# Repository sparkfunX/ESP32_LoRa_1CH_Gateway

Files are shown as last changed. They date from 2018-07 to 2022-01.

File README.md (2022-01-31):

SparkX ESP32 LoRa Single-Channel Gateway
========================================

This repo is the original SparkX version. Please see the [SparkFun repo](https://github.com/sparkfun/ESP32_LoRa_1Ch_Gateway/) for the latest and greatest.

SparkX ESP32 LoRa Single-Channel Gateway (https://www.sparkfun.com/products/14893)

[*SparkX  ESP32 LoRa Single-Channel Gateway (SPX-14893)*](https://www.sparkfun.com/products/14893)

The SparkX ESP32 LoRa Single-Channel Gateway combines an ESP32 -- a programmable microcontroller featuring both WiFi and Bluetooth radios -- with an RFM95W LoRa transceiver to create a single-channel LoRa gateway. It's a perfect, low-cost tool for monitoring a dozen-or-so LoRa devices, and relaying their messages up to the cloud.

Complete with a [Qwiic connector](https://www.sparkfun.com/qwiic) and a breadboard-compatible array of ESP32 pin-breakouts, this board can can also serve as a general-purpose ESP32/RFM95W development platform. So, instead of using it as a LoRaWAN gateway, you can turn it into a **LoRa device**, and use the powerful ESP32 microcontroller to monitor sensors, host a web server, run a display or more.

These boards are a great way to begin dipping your toes into the world of LoRa and LoRaWAN. Not only can they be programmed as versatile single-channel gateway, but they can also be used as a LoRa device, or a general ESP32/RFM95W development board.

For more information, check out our [ESP32 LoRa 1-CH Gateway, LoRaWAN, and the Things Network](https://learn.sparkfun.com/tutorials/esp32-lora-1-ch-gateway-lorawan-and-the-things-network) tutorial, which explains how to set the board up, and get it connected to The Things Network.

SparkFun labored with love to create this code. Feel like supporting open source hardware? 
Buy a [breakout board](https://www.sparkfun.com/products/14893) from SparkFun!

Repository Contents
-------------------

* **/Documents** - Datasheets
* **/Hardware** - Eagle design files (.brd, .sch)
* **/Firmware** - Example code and esp32-Arduino board files

License Information
-------------------

This product is _**open source**_! 

If you have any questions or concerns on licensing, please contact techsupport@sparkfun.com.

Please use, reuse, and modify these files as you see fit. Please maintain attribution to SparkFun Electronics and release any derivative under the same license.

Distributed as-is; no warranty is given.

- Your friends at SparkFun.

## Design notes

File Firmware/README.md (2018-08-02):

Software directory contents
===========================

* **ESP-1CH-TTN-Device-ABP** -- Arduino example sketch implementing a single-channel LoRaWAN device with ABP activation.
	* Depends on the [Arduino-LMIC library](https://github.com/mcci-catena/arduino-lmic).
* **arduino-esp32** -- board.txt and pin-variant files to add the SparkX ESP32 LoRa 1-CH Gateway to the ESP32 Arduino core
	* Depends on the [Arduino Core for ESP32 WiFi chip](https://github.com/espressif/arduino-esp32)

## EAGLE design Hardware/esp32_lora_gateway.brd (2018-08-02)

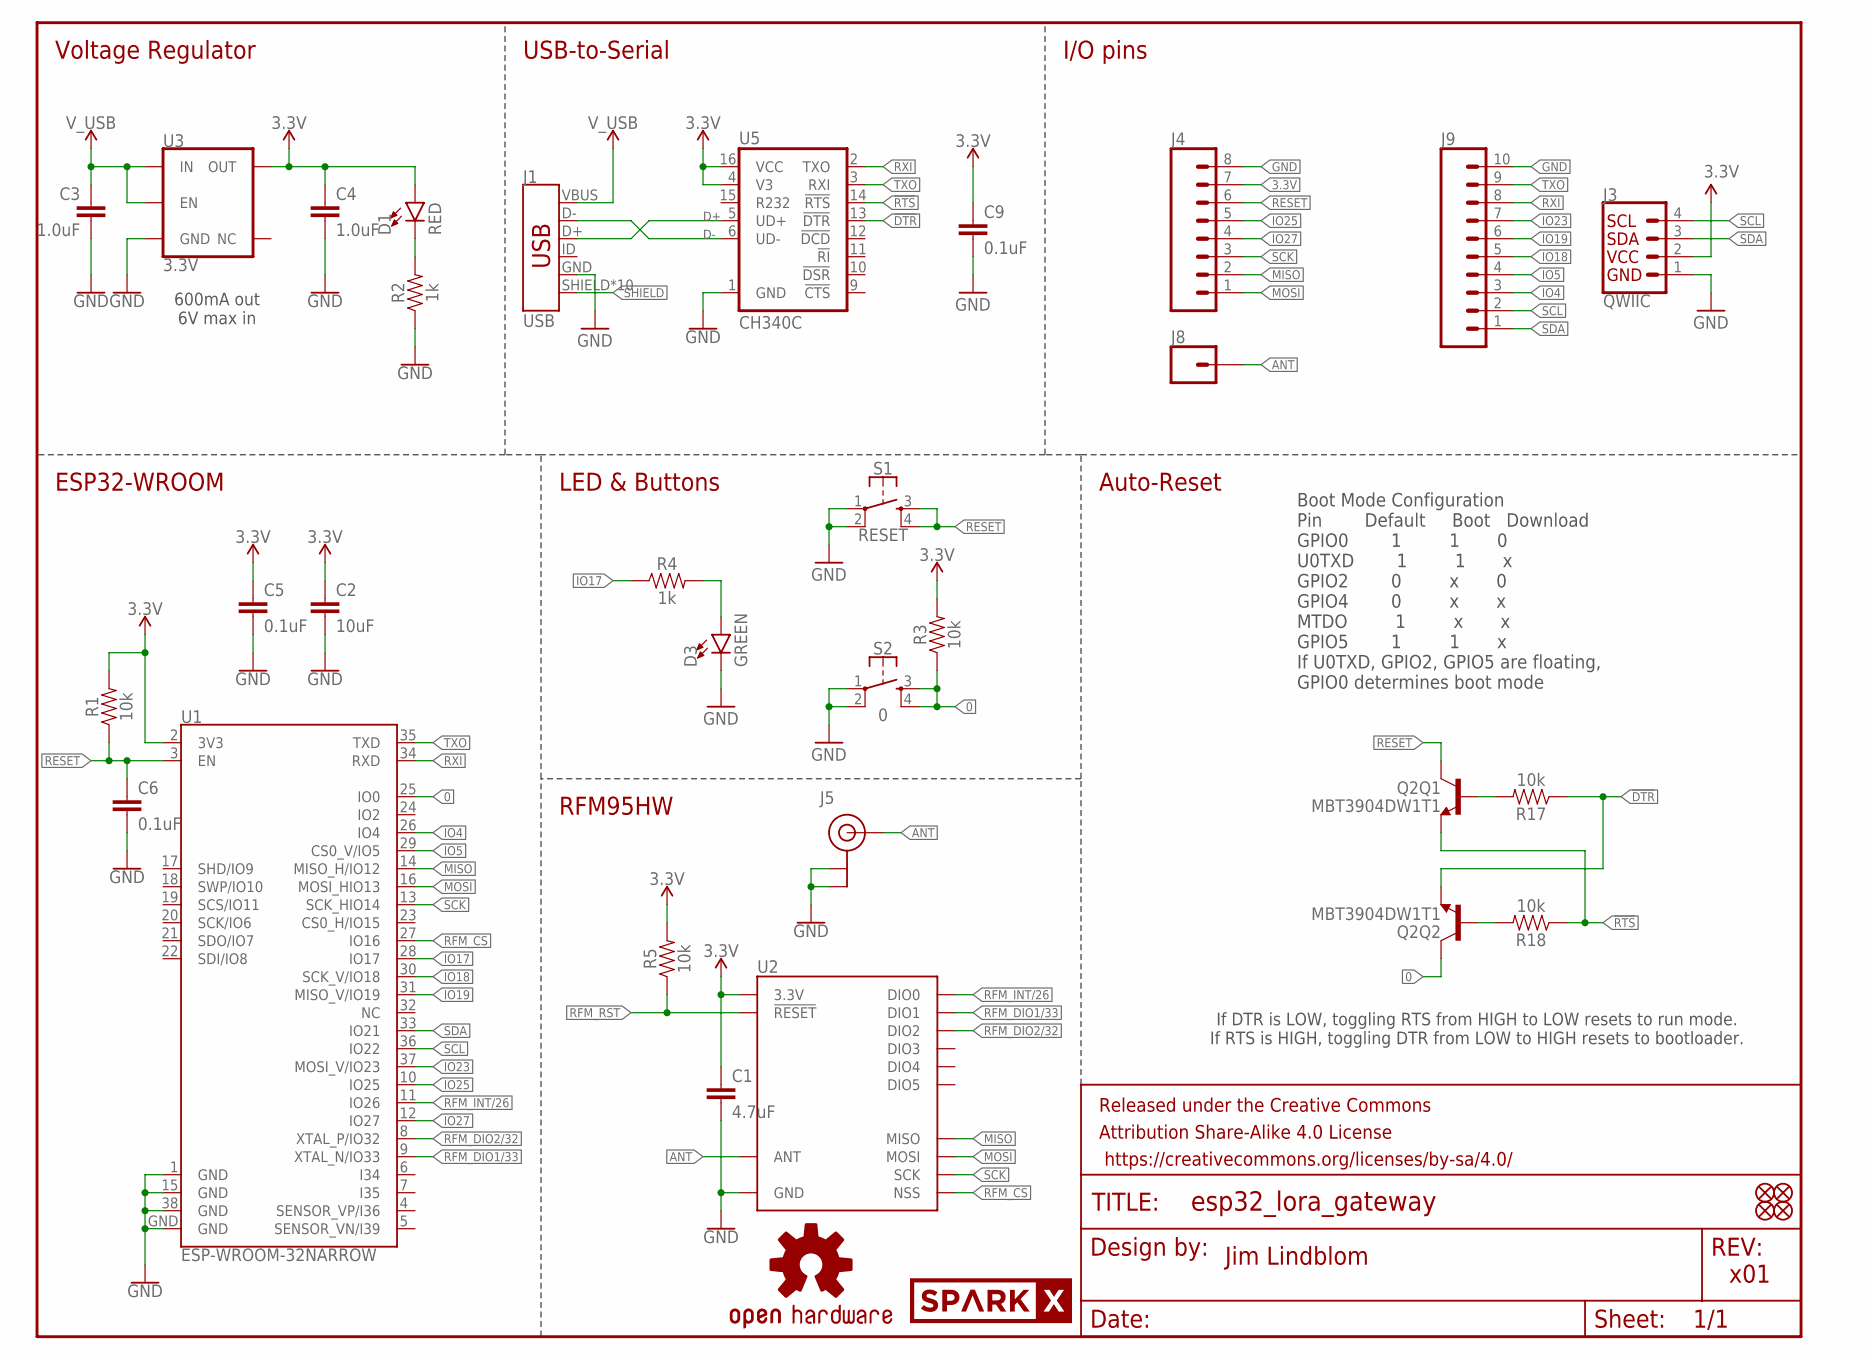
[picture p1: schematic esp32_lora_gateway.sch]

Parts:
C1: 4.7uF; 0603
C2: 10uF; 0603
C3, C4: 1.0uF; 0603
C5, C6: 0.1uF; 0603
C9: 0.1uF; 0603-CAP
D1: RED; LED-0603
D3: GREEN; LED-0603
FD1, FD2, FD3, FD4: FIDUCIALUFIDUCIAL; FIDUCIAL-MICRO
FRAME1: FRAME-LETTER; CREATIVE_COMMONS
J1: USB; USB-MICROB-PTH-MILL
J3: QWIIC; 1X04_1MM_RA
J4: CONN_08NO_SILK_FEMALE_PTH; 1X08_NO_SILK
J5: U.FL
J8: CONN_01PTH_NO_SILK_YES_STOP; 1X01_NO_SILK
J9: CONN_10NO_SILK_PTH_FEMALE; 1X10_NO_SILK
LOGO1: SPARKX-LOGO4; SPARKX-MEDIUM
LOGO2: OSHW-LOGOM; OSHW-LOGO-M
Q2: MBT3904DW1T1; SC70-6
R1, R3, R5, R17, R18: 10k; 0603
R2, R4: 1k; 0603
S1: RESET; TACTILE_SWITCH_SMD_4.6X2.8MM
S2: 0; TACTILE_SWITCH_SMD_4.6X2.8MM
U1: ESP-WROOM-32NARROW; ESP-WROOM-32-NARROW
U2: RFM96W; RFM95/96/97/98W
U3: 3.3V; SOT23-5
U5: CH340C; SO016

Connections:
0: Q2.6 (C), R3.1, S2.3, S2.4, U1.25 (IO0)
3.3V: C1.1, C2.1, C4.1, C5.1, C9.1, D1.A, J3.2, J4.7, R1.2, R3.2, R5.2, U1.2 (3V3), U2.3.3V, U3.5 (OUT), U5.4 (V3), U5.16 (VCC)
!DTR: Q2.1 (E), R17.1, U5.13 (!DTR)
!RTS: Q2.4 (E), R18.1, U5.14 (!RTS)
ANT: J5.FEED (SIGNAL), J8.1, U2.ANT
D+: J1.D+, U5.5 (UD+)
D-: J1.D-, U5.6 (UD-)
GND: C1.2, C2.2, C3.2, C4.2, C5.2, C6.2, C9.2, D3.C, J1.GND, J3.1, J4.8, J5.1 (GND), J5.2 (GND), J9.10, R2.1, S1.1, S1.2, S2.1, S2.2, U1.1 (GND), U1.15 (GND), U1.38 (GND), U1.GND, U2.GND@1 (GND), U2.GND@2 (GND), U2.GND@3 (GND), U3.2 (GND), U5.1 (GND)
IO4: J9.3, U1.26 (IO4)
IO5: J9.4, U1.29 (CS0_V/IO5)
IO17: R4.1, U1.28 (IO17)
IO18: J9.5, U1.30 (SCK_V/IO18)
IO19: J9.6, U1.31 (MISO_V/IO19)
IO23: J9.7, U1.37 (MOSI_V/IO23)
IO25: J4.5, U1.10 (IO25)
IO27: J4.4, U1.12 (IO27)
MISO: J4.2, U1.14 (MISO_H/IO12), U2.MISO
MOSI: J4.1, U1.16 (MOSI_HIO13), U2.MOSI
unnamed: D1.C, R2.2
unnamed: D3.A, R4.2
unnamed: Q2.5 (B), R17.2
unnamed: Q2.2 (B), R18.2
RESET: C6.1, J4.6, Q2.3 (C), R1.1, S1.3, S1.4, U1.3 (EN)
RFM_CS: U1.27 (IO16), U2.NSS
RFM_DIO1/33: U1.9 (XTAL_N/IO33), U2.DIO1
RFM_DIO2/32: U1.8 (XTAL_P/IO32), U2.DIO2
RFM_INT/26: U1.11 (IO26), U2.DIO0
RFM_RST: R5.1, U2.!RESET
RXI: J9.8, U1.34 (RXD), U5.2 (TXO)
SCK: J4.3, U1.13 (SCK_HIO14), U2.SCK
SCL: J3.4, J9.2, U1.36 (IO22)
SDA: J3.3, J9.1, U1.33 (IO21)
SHIELD: J1.SHIELD, J1.SHIELD2 (SHIELD), J1.SHIELD3 (SHIELD), J1.SHIELD4 (SHIELD), J1.SHIELD5 (SHIELD), J1.SHIELD6 (SHIELD), J1.SHIELD7 (SHIELD), J1.SHIELD8 (SHIELD), J1.SHIELD9 (SHIELD), J1.SHIELD10 (SHIELD)
TXO: J9.9, U1.35 (TXD), U5.3 (RXI)
V_USB: C3.1, J1.VBUS, U3.1 (IN), U3.3 (EN)

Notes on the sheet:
Boot Mode Configuration Pin Default Boot Download GPIO0 1 1 0 U0TXD 1 1 x GPIO2 0 x 0 GPIO4 0 x x MTDO 1 x x GPIO5 1 1 x If U0TXD, GPIO2, GPIO5 are floating, GPIO0 determines boot mode
If DTR is LOW, toggling RTS from HIGH to LOW resets to run mode. If RTS is HIGH, toggling DTR from LOW to HIGH resets to bootloader.
600mA out 6V max in
Voltage Regulator
USB-to-Serial
I/O pins
ESP32-WROOM
LED & Buttons
Auto-Reset
RFM95HW
Jim Lindblom
x01

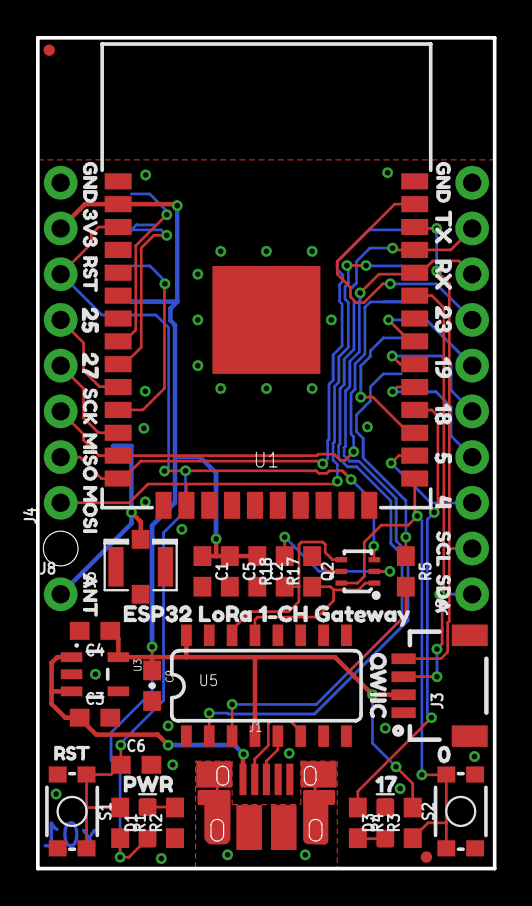
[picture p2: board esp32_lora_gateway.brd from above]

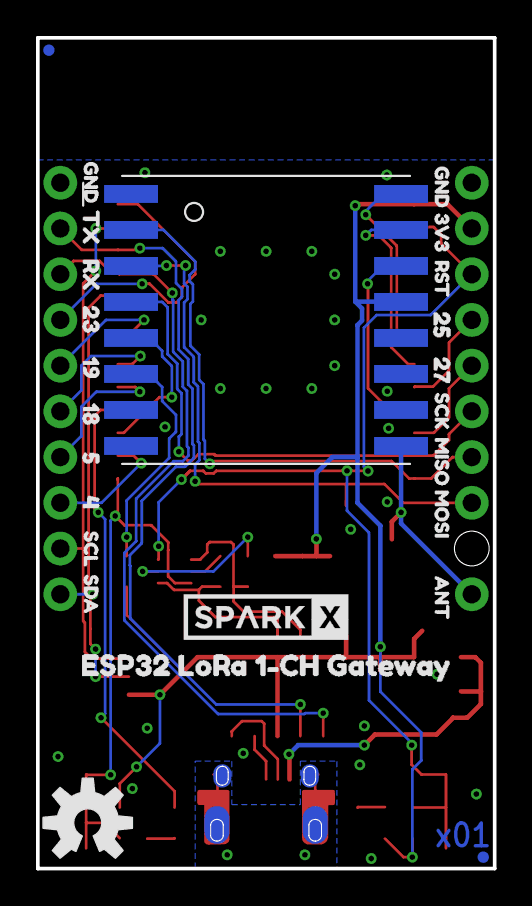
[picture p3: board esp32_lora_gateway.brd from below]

Board: 2 copper layers, 25.4 x 46.2 mm, 81 parts (25 on the bottom side), 35 nets.

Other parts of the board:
U$1, U$10, U$26, U$37: GND0
U$2, U$38: 3V31
U$3, U$20, U$39: RST2
U$4, U$40: 2517
U$5, U$41: 279
U$6, U$42: SCK3
U$7, U$43: MISO4
U$8, U$44: MOSI5
U$9, U$36: ANT6
U$11, U$27: TX16
U$12, U$28: RX15
U$13, U$29: 2314
U$14, U$30: 1912
U$15, U$31: 1811
U$16, U$32: 513
U$17, U$33: 410
U$18, U$34: SCL8
U$19, U$35: SDA7
U$21: 020
U$22: PWR19
U$23: 1722
U$24: QWIIC18
U$25: ESP32_LORA_1#CH_GATEWAY21
U$45: ESP32_LORA_1#CH_GATEWAY23

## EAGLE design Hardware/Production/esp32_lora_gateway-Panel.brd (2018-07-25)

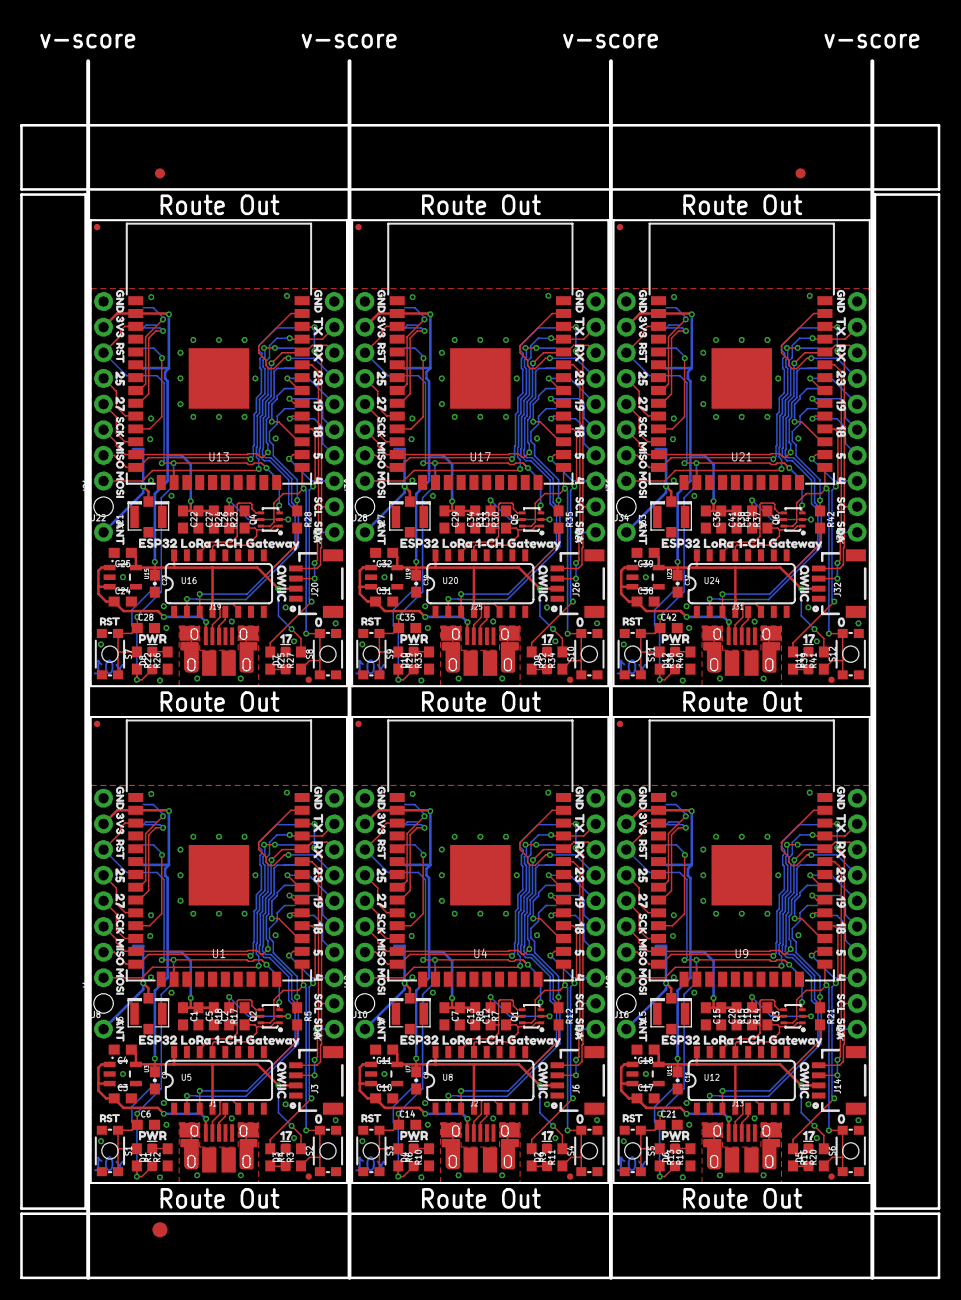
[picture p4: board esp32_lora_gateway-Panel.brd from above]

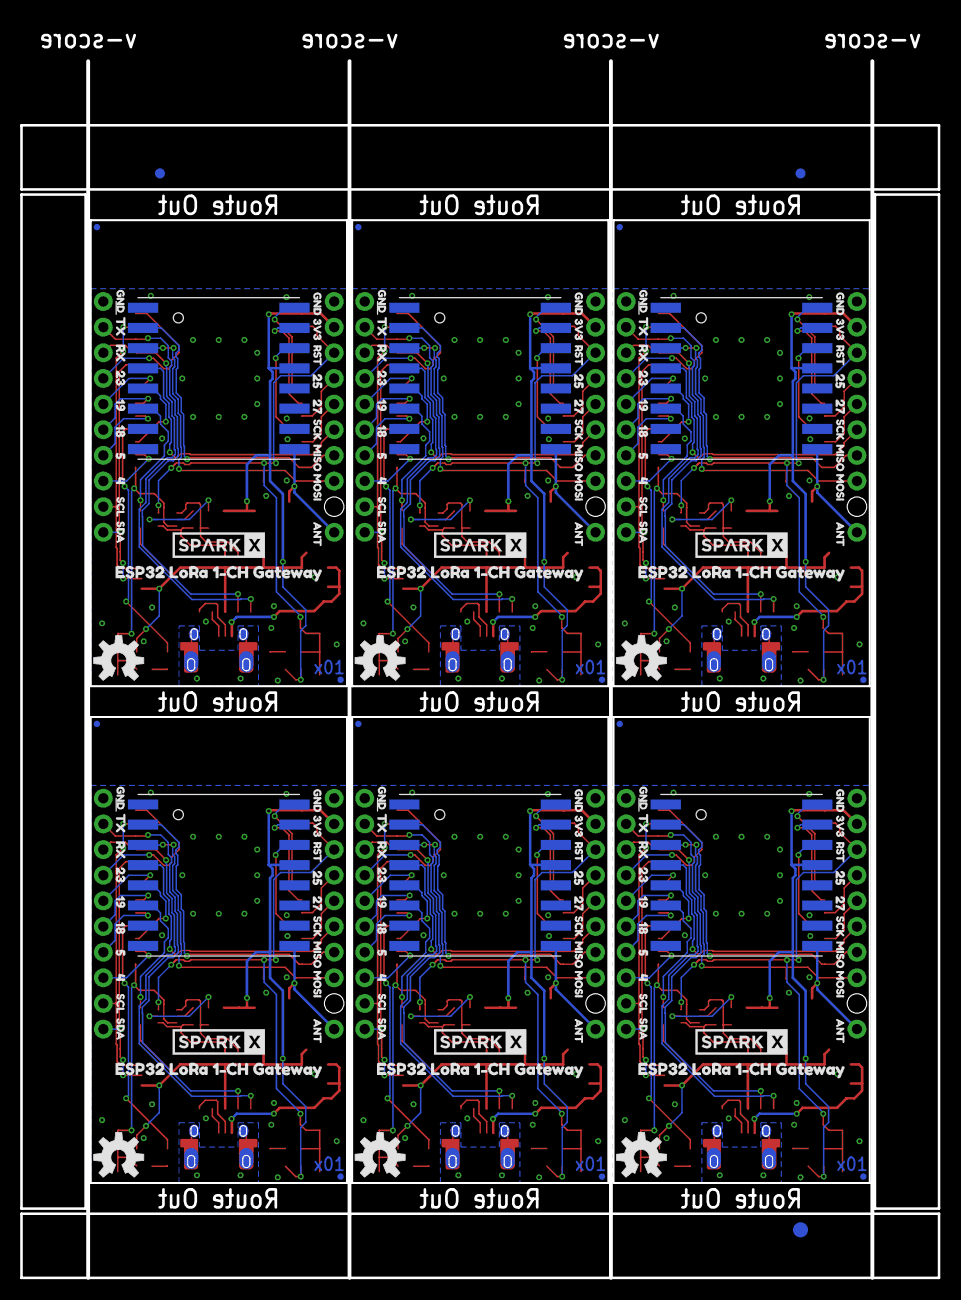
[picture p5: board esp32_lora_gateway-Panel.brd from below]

Board: 2 copper layers, 90.9 x 120.5 mm, 486 parts (153 on the bottom side), 210 nets.

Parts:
C1, C7, C15, C22, C29, C36: 4.7uF; 0603
C2, C12, C19, C26, C33, C40: 10uF; 0603
C3, C4, C10, C11, C17, C18, C24, C25, C31, C32, C38, C39: 1.0uF; 0603
C5, C6, C13, C14, C20, C21, C27, C28, C34, C35, C41, C42: 0.1uF; 0603
C8, C9, C16, C23, C30, C37: 0.1uF; 0603-CAP
D1, D4, D6, D8, D10, D12: RED; LED-0603
D2, D3, D5, D7, D9, D11: GREEN; LED-0603
E$1, E$2, E$3, E$4: FIDUCIAL-1X2
E$5, E$6: FIDUCIAL-1.5X3
FD1, FD2, FD3, FD4, FD5, FD6, FD7, FD8, FD9, FD10, FD11, FD12, FD13, FD14, FD15, FD16, FD17, FD18, FD19, FD20, FD21, FD22, FD23, FD24: FIDUCIALUFIDUCIAL; FIDUCIAL-MICRO
J1, J2, J13, J19, J25, J31: USB-MICROB-PTH-MILL
J3, J6, J14, J20, J26, J32: 1X04_1MM_RA
J4, J12, J18, J24, J30, J36: 1X08_NO_SILK
J5, J7, J15, J21, J27, J33: U.FL
J8, J10, J16, J22, J28, J34: 1X01_NO_SILK
J9, J11, J17, J23, J29, J35: 1X10_NO_SILK
LOGO1, LOGO3, LOGO5, LOGO7, LOGO9, LOGO11: SPARKX-LOGO4; SPARKX-MEDIUM
LOGO2, LOGO4, LOGO6, LOGO8, LOGO10, LOGO12: OSHW-LOGOM; OSHW-LOGO-M
Q1, Q2, Q3, Q4, Q5, Q6: MBT3904DW1T1; SC70-6
R1, R3, R5, R6, R7, R8, R11, R12, R13, R14, R15, R17, R18, R20, R21, R22, R23, R24, R27, R28, R29, R30, R31, R34, R35, R36, R37, R38, R41, R42: 10k; 0603
R2, R4, R9, R10, R16, R19, R25, R26, R32, R33, R39, R40: 1k; 0603
S1, S2, S3, S4, S5, S6, S7, S8, S9, S10, S11, S12: RESET; TACTILE_SWITCH_SMD_4.6X2.8MM
U1, U4, U9, U13, U17, U21: ESP-WROOM-32NARROW; ESP-WROOM-32-NARROW
U2, U6, U10, U14, U18, U22: RFM96W; RFM95/96/97/98W
U3, U7, U11, U15, U19, U23: 3.3V; SOT23-5
U5, U8, U12, U16, U20, U24: CH340C; SO016
U$1, U$10, U$26, U$37, U$47, U$55, U$71, U$82, U$92, U$100, U$116, U$127, U$137, U$145, U$161, U$172, U$182, U$190, U$206, U$217, U$227, U$235, U$251, U$262: GND0
U$2, U$38, U$48, U$83, U$93, U$128, U$138, U$173, U$183, U$218, U$228, U$263: 3V31
U$3, U$20, U$39, U$49, U$65, U$84, U$94, U$110, U$129, U$139, U$155, U$174, U$184, U$200, U$219, U$229, U$245, U$264: RST2
U$4, U$40, U$50, U$85, U$95, U$130, U$140, U$175, U$185, U$220, U$230, U$265: 2517
U$5, U$41, U$51, U$86, U$96, U$131, U$141, U$176, U$186, U$221, U$231, U$266: 279
U$6, U$42, U$52, U$87, U$97, U$132, U$142, U$177, U$187, U$222, U$232, U$267: SCK3
U$7, U$43, U$53, U$88, U$98, U$133, U$143, U$178, U$188, U$223, U$233, U$268: MISO4
U$8, U$44, U$54, U$89, U$99, U$134, U$144, U$179, U$189, U$224, U$234, U$269: MOSI5
U$9, U$36, U$46, U$81, U$91, U$126, U$136, U$171, U$181, U$216, U$226, U$261: ANT6
U$11, U$27, U$56, U$72, U$101, U$117, U$146, U$162, U$191, U$207, U$236, U$252: TX16
U$12, U$28, U$57, U$73, U$102, U$118, U$147, U$163, U$192, U$208, U$237, U$253: RX15
U$13, U$29, U$58, U$74, U$103, U$119, U$148, U$164, U$193, U$209, U$238, U$254: 2314
U$14, U$30, U$59, U$75, U$104, U$120, U$149, U$165, U$194, U$210, U$239, U$255: 1912
U$15, U$31, U$60, U$76, U$105, U$121, U$150, U$166, U$195, U$211, U$240, U$256: 1811
U$16, U$32, U$61, U$77, U$106, U$122, U$151, U$167, U$196, U$212, U$241, U$257: 513
U$17, U$33, U$62, U$78, U$107, U$123, U$152, U$168, U$197, U$213, U$242, U$258: 410
U$18, U$34, U$63, U$79, U$108, U$124, U$153, U$169, U$198, U$214, U$243, U$259: SCL8
U$19, U$35, U$64, U$80, U$109, U$125, U$154, U$170, U$199, U$215, U$244, U$260: SDA7
U$21, U$66, U$111, U$156, U$201, U$246: 020
U$22, U$67, U$112, U$157, U$202, U$247: PWR19
U$23, U$68, U$113, U$158, U$203, U$248: 1722
U$24, U$69, U$114, U$159, U$204, U$249: QWIIC18
U$25, U$70, U$115, U$160, U$205, U$250: ESP32_LORA_1#CH_GATEWAY21
U$45, U$90, U$135, U$180, U$225, U$270: ESP32_LORA_1#CH_GATEWAY23

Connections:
0: Q2.6, R3.1, S2.3, S2.4, U1.25
1: Q1.6, R11.1, S4.3, S4.4, U4.25
2: Q3.6, R20.1, S6.3, S6.4, U9.25
3: Q4.6, R27.1, S8.3, S8.4, U13.25
3.3V: C1.1, C2.1, C4.1, C5.1, C9.1, D1.A, J3.2, J4.7, R1.2, R3.2, R5.2, U1.2, U2.3.3V, U3.5, U5.4, U5.16
3.3V1: C7.1, C8.1, C11.1, C12.1, C13.1, D4.A, J6.2, J12.7, R6.2, R11.2, R12.2, U4.2, U6.3.3V, U7.5, U8.4, U8.16
3.3V2: C15.1, C16.1, C18.1, C19.1, C20.1, D6.A, J14.2, J18.7, R13.2, R20.2, R21.2, U9.2, U10.3.3V, U11.5, U12.4, U12.16
3.3V3: C22.1, C23.1, C25.1, C26.1, C27.1, D8.A, J20.2, J24.7, R22.2, R27.2, R28.2, U13.2, U14.3.3V, U15.5, U16.4, U16.16
3.3V4: C29.1, C30.1, C32.1, C33.1, C34.1, D10.A, J26.2, J30.7, R29.2, R34.2, R35.2, U17.2, U18.3.3V, U19.5, U20.4, U20.16
3.3V5: C36.1, C37.1, C39.1, C40.1, C41.1, D12.A, J32.2, J36.7, R36.2, R41.2, R42.2, U21.2, U22.3.3V, U23.5, U24.4, U24.16
4: Q5.6, R34.1, S10.3, S10.4, U17.25
5: Q6.6, R41.1, S12.3, S12.4, U21.25
!DTR: Q2.1, R17.1, U5.13
!DTR1: Q1.1, R7.1, U8.13
!DTR2: Q3.1, R14.1, U12.13
!DTR3: Q4.1, R23.1, U16.13
!DTR4: Q5.1, R30.1, U20.13
!DTR5: Q6.1, R37.1, U24.13
!RTS: Q2.4, R18.1, U5.14
!RTS1: Q1.4, R8.1, U8.14
!RTS2: Q3.4, R15.1, U12.14
!RTS3: Q4.4, R24.1, U16.14
!RTS4: Q5.4, R31.1, U20.14
!RTS5: Q6.4, R38.1, U24.14
ANT: J5.FEED, J8.1, U2.ANT
ANT1: J7.FEED, J10.1, U6.ANT
ANT2: J15.FEED, J16.1, U10.ANT
ANT3: J21.FEED, J22.1, U14.ANT
ANT4: J27.FEED, J28.1, U18.ANT
ANT5: J33.FEED, J34.1, U22.ANT
D+: J1.D+, U5.5
D+1: J2.D+, U8.5
D+2: J13.D+, U12.5
D+3: J19.D+, U16.5
D+4: J25.D+, U20.5
D+5: J31.D+, U24.5
D-: J1.D-, U5.6
D-1: J2.D-, U8.6
D-2: J13.D-, U12.6
D-3: J19.D-, U16.6
D-4: J25.D-, U20.6
D-5: J31.D-, U24.6
GND: C1.2, C2.2, C3.2, C4.2, C5.2, C6.2, C9.2, D3.C, J1.GND, J3.1, J4.8, J5.1, J5.2, J9.10, R2.1, S1.1, S1.2, S2.1, S2.2, U1.1, U1.15, U1.38, U1.GND, U2.GND@1, U2.GND@2, U2.GND@3, U3.2, U5.1
GND1: C7.2, C8.2, C10.2, C11.2, C12.2, C13.2, C14.2, D2.C, J2.GND, J6.1, J7.1, J7.2, J11.10, J12.8, R10.1, S3.1, S3.2, S4.1, S4.2, U4.1, U4.15, U4.38, U4.GND, U6.GND@1, U6.GND@2, U6.GND@3, U7.2, U8.1
GND2: C15.2, C16.2, C17.2, C18.2, C19.2, C20.2, C21.2, D5.C, J13.GND, J14.1, J15.1, J15.2, J17.10, J18.8, R19.1, S5.1, S5.2, S6.1, S6.2, U9.1, U9.15, U9.38, U9.GND, U10.GND@1, U10.GND@2, U10.GND@3, U11.2, U12.1
GND3: C22.2, C23.2, C24.2, C25.2, C26.2, C27.2, C28.2, D7.C, J19.GND, J20.1, J21.1, J21.2, J23.10, J24.8, R26.1, S7.1, S7.2, S8.1, S8.2, U13.1, U13.15, U13.38, U13.GND, U14.GND@1, U14.GND@2, U14.GND@3, U15.2, U16.1
GND4: C29.2, C30.2, C31.2, C32.2, C33.2, C34.2, C35.2, D9.C, J25.GND, J26.1, J27.1, J27.2, J29.10, J30.8, R33.1, S9.1, S9.2, S10.1, S10.2, U17.1, U17.15, U17.38, U17.GND, U18.GND@1, U18.GND@2, U18.GND@3, U19.2, U20.1
GND5: C36.2, C37.2, C38.2, C39.2, C40.2, C41.2, C42.2, D11.C, J31.GND, J32.1, J33.1, J33.2, J35.10, J36.8, R40.1, S11.1, S11.2, S12.1, S12.2, U21.1, U21.15, U21.38, U21.GND, U22.GND@1, U22.GND@2, U22.GND@3, U23.2, U24.1
IO1: J12.5, U4.10
IO2: J12.4, U4.12
IO3: J11.6, U4.31
IO4: J9.3, U1.26
IO5: J9.4, U1.29
IO6: J11.5, U4.30
IO7: J11.4, U4.29
IO8: J11.7, U4.37
IO9: J11.3, U4.26
IO10: R9.1, U4.28
IO11: J18.5, U9.10
IO12: J18.4, U9.12
IO13: J17.6, U9.31
IO14: J17.5, U9.30
IO15: J17.4, U9.29
IO16: J17.7, U9.37
IO17: R4.1, U1.28
IO18: J9.5, U1.30
IO19: J9.6, U1.31
IO20: J17.3, U9.26
IO21: R16.1, U9.28
IO22: J24.5, U13.10
IO23: J9.7, U1.37
IO24: J24.4, U13.12
IO25: J4.5, U1.10
IO26: J23.6, U13.31
IO27: J4.4, U1.12
IO28: J23.5, U13.30
IO29: J23.4, U13.29
IO30: J23.7, U13.37
IO31: J23.3, U13.26
IO32: R25.1, U13.28
IO33: J30.5, U17.10
IO34: J30.4, U17.12
IO35: J29.6, U17.31
IO36: J29.5, U17.30
IO37: J29.4, U17.29
IO38: J29.7, U17.37
IO39: J29.3, U17.26
IO40: R32.1, U17.28
IO41: J36.5, U21.10
IO42: J36.4, U21.12
IO43: J35.6, U21.31
IO44: J35.5, U21.30
IO45: J35.4, U21.29
IO46: J35.7, U21.37
IO47: J35.3, U21.26
IO48: R39.1, U21.28
MISO: J4.2, U1.14, U2.MISO
MISO1: J12.2, U4.14, U6.MISO
MISO2: J18.2, U9.14, U10.MISO
MISO3: J24.2, U13.14, U14.MISO
MISO4: J30.2, U17.14, U18.MISO
MISO5: J36.2, U21.14, U22.MISO
MOSI: J4.1, U1.16, U2.MOSI
MOSI1: J12.1, U4.16, U6.MOSI
MOSI2: J18.1, U9.16, U10.MOSI
MOSI3: J24.1, U13.16, U14.MOSI
MOSI4: J30.1, U17.16, U18.MOSI
MOSI5: J36.1, U21.16, U22.MOSI
unnamed: D1.C, R2.2
unnamed: D3.A, R4.2
unnamed: Q1.5, R7.2
unnamed: Q1.2, R8.2
unnamed: D2.A, R9.2
unnamed: D4.C, R10.2
unnamed: Q3.5, R14.2
unnamed: Q3.2, R15.2
unnamed: D5.A, R16.2
unnamed: Q2.5, R17.2
unnamed: D6.C, R19.2
unnamed: Q2.2, R18.2
unnamed: Q4.5, R23.2
unnamed: Q4.2, R24.2
unnamed: D7.A, R25.2
unnamed: D8.C, R26.2
unnamed: Q5.5, R30.2
unnamed: Q5.2, R31.2
unnamed: D9.A, R32.2
unnamed: D10.C, R33.2
unnamed: Q6.5, R37.2
unnamed: Q6.2, R38.2
unnamed: D11.A, R39.2
unnamed: D12.C, R40.2
RESET: C6.1, J4.6, Q2.3, R1.1, S1.3, S1.4, U1.3
RESET1: C14.1, J12.6, Q1.3, R6.1, S3.3, S3.4, U4.3
RESET2: C21.1, J18.6, Q3.3, R13.1, S5.3, S5.4, U9.3
RESET3: C28.1, J24.6, Q4.3, R22.1, S7.3, S7.4, U13.3
RESET4: C35.1, J30.6, Q5.3, R29.1, S9.3, S9.4, U17.3
RESET5: C42.1, J36.6, Q6.3, R36.1, S11.3, S11.4, U21.3
RFM_CS: U1.27, U2.NSS
RFM_CS1: U4.27, U6.NSS
RFM_CS2: U9.27, U10.NSS
RFM_CS3: U13.27, U14.NSS
RFM_CS4: U17.27, U18.NSS
RFM_CS5: U21.27, U22.NSS
RFM_DIO1/1: U4.9, U6.DIO1
RFM_DIO1/2: U9.9, U10.DIO1
RFM_DIO1/3: U13.9, U14.DIO1
RFM_DIO1/4: U17.9, U18.DIO1
RFM_DIO1/5: U21.9, U22.DIO1
RFM_DIO1/33: U1.9, U2.DIO1
RFM_DIO2/1: U4.8, U6.DIO2
RFM_DIO2/2: U9.8, U10.DIO2
RFM_DIO2/3: U13.8, U14.DIO2
RFM_DIO2/4: U17.8, U18.DIO2
RFM_DIO2/5: U21.8, U22.DIO2
RFM_DIO2/32: U1.8, U2.DIO2
RFM_INT/1: U4.11, U6.DIO0
RFM_INT/2: U9.11, U10.DIO0
RFM_INT/3: U13.11, U14.DIO0
RFM_INT/4: U17.11, U18.DIO0
RFM_INT/5: U21.11, U22.DIO0
RFM_INT/26: U1.11, U2.DIO0
RFM_RST: R5.1, U2.!RESET
RFM_RST1: R12.1, U6.!RESET
RFM_RST2: R21.1, U10.!RESET
RFM_RST3: R28.1, U14.!RESET
RFM_RST4: R35.1, U18.!RESET
RFM_RST5: R42.1, U22.!RESET
RXI: J9.8, U1.34, U5.2
RXI1: J11.8, U4.34, U8.2
RXI2: J17.8, U9.34, U12.2
RXI3: J23.8, U13.34, U16.2
RXI4: J29.8, U17.34, U20.2
RXI5: J35.8, U21.34, U24.2
SCK: J4.3, U1.13, U2.SCK
SCK1: J12.3, U4.13, U6.SCK
SCK2: J18.3, U9.13, U10.SCK
SCK3: J24.3, U13.13, U14.SCK
SCK4: J30.3, U17.13, U18.SCK
SCK5: J36.3, U21.13, U22.SCK
SCL: J3.4, J9.2, U1.36
SCL1: J6.4, J11.2, U4.36
SCL2: J14.4, J17.2, U9.36
SCL3: J20.4, J23.2, U13.36
SCL4: J26.4, J29.2, U17.36
SCL5: J32.4, J35.2, U21.36
SDA: J3.3, J9.1, U1.33
SDA1: J6.3, J11.1, U4.33
SDA2: J14.3, J17.1, U9.33
SDA3: J20.3, J23.1, U13.33
SDA4: J26.3, J29.1, U17.33
SDA5: J32.3, J35.1, U21.33
SHIELD: J1.SHIELD, J1.SHIELD2, J1.SHIELD3, J1.SHIELD4, J1.SHIELD5, J1.SHIELD6, J1.SHIELD7, J1.SHIELD8, J1.SHIELD9, J1.SHIELD10
SHIELD1: J2.SHIELD, J2.SHIELD2, J2.SHIELD3, J2.SHIELD4, J2.SHIELD5, J2.SHIELD6, J2.SHIELD7, J2.SHIELD8, J2.SHIELD9, J2.SHIELD10
SHIELD2: J13.SHIELD, J13.SHIELD2, J13.SHIELD3, J13.SHIELD4, J13.SHIELD5, J13.SHIELD6, J13.SHIELD7, J13.SHIELD8, J13.SHIELD9, J13.SHIELD10
SHIELD3: J19.SHIELD, J19.SHIELD2, J19.SHIELD3, J19.SHIELD4, J19.SHIELD5, J19.SHIELD6, J19.SHIELD7, J19.SHIELD8, J19.SHIELD9, J19.SHIELD10
SHIELD4: J25.SHIELD, J25.SHIELD2, J25.SHIELD3, J25.SHIELD4, J25.SHIELD5, J25.SHIELD6, J25.SHIELD7, J25.SHIELD8, J25.SHIELD9, J25.SHIELD10
SHIELD5: J31.SHIELD, J31.SHIELD2, J31.SHIELD3, J31.SHIELD4, J31.SHIELD5, J31.SHIELD6, J31.SHIELD7, J31.SHIELD8, J31.SHIELD9, J31.SHIELD10
TXO: J9.9, U1.35, U5.3
TXO1: J11.9, U4.35, U8.3
TXO2: J17.9, U9.35, U12.3
TXO3: J23.9, U13.35, U16.3
TXO4: J29.9, U17.35, U20.3
TXO5: J35.9, U21.35, U24.3
V_USB: C3.1, J1.VBUS, U3.1, U3.3
V_USB1: C10.1, J2.VBUS, U7.1, U7.3
V_USB2: C17.1, J13.VBUS, U11.1, U11.3
V_USB3: C24.1, J19.VBUS, U15.1, U15.3
V_USB4: C31.1, J25.VBUS, U19.1, U19.3
V_USB5: C38.1, J31.VBUS, U23.1, U23.3

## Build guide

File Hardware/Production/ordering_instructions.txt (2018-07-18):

panel size, 91x115mm
PCB thickness, 1.6mm
number of layers, 2
soldermask color, Black
silkscreen color, White
oz copper, 1oz
finish, HASL lead free
stencils, top+bottom
pcs per panel, 6

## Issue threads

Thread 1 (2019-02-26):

Probelms to upload the gateway example.

guillermoamorin, 2019-02-26:
Hi, I am following the next tutorial :

hhttps://learn.sparkfun.com/tutorials/esp32-lora-1-ch-gateway-lorawan-and-the-things-network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 and I can't even upload the sketch.

After a few trials, I change the arduino ide board option from "SparkX ESP32 LoRa Gateway" to "Esp 32 Dev Moule" and the upload speed from 921600 to 115200 and I finaly could upload the sketch.

But when I acces to tthe Serial Monitor, the log it shows repeteadly is:

ets Jun  8 2016 00:22:57

rst:0x1 (POWERON_RESET),boot:0x13 (S.ets Jun  8 2016 00:22:57

rst:0x1 (POWERON_RESET),boot:0x13 (SPI_FAST_FLASH_BOOT)
configsip: 0, SPIWP:0xee
clk_drv:0x00,q_drv:0x00,d_drv:0x00,cs0_drv:0x00,hd_drv:0x00,wp_drv:0x00
mode:DIO, clock div:1
load:0x3fff0018,len:4
load:0x3fff001c,len:1100
load:0x40078000,len:10088
load:0x40080400,len:6380
entry 0x400806a4
ESP32 defined, freq=
ARDUINO_ARCH_ESP32 defined
SPIFFS init success
Assert=Do Asserts
debug=1
readConfig:: Starting
.SSID=	wifing
.PASS=	wifing-pub
.CH=	0
.SF=	9
.FCNT=	0
.DEBUG=	1
.PDEBUG=64
.CAD=1
.HOP=0
.NODE=	0
.BOOTS=	21
.RESETS=	0
.WIFIS=	21
.VIEWS=	0
.REFR=	0
.REENTS=	0
.NTPETIM=	0
.NTPERR=	0
.NTPS=	21
.FILEREC=	0
.FILENO=	0
.FILENUM=	0
.EXPERT=	0
#

MAC: 84:0d:8e:07:56:8c, len=17
WlanConnect:: Init para 0
0:1:3. WiFi connect SSID=wifing, pass=wifing-pub
A WlanStatus:: CONNECTED to wifing
Host esp32-07568c WiFi Connected to wifing on IP=172.16.106.63
Local UDP port=1700
Connection successful
Gateway ID: 840D8EFFFF07568C, Listening at SF9 on 903.90 Mhz.
setupOta:: Started
Ready
IP address: 172.16.106.63
Time: Tuesday 23:45:31
Gateway configuration saved
WWW Server started on port 80
Unknown transceiver=0, pins.rst =27, pins.ss  =16, pins.dio0 =26, pins.dio1 =33, pins.dio2 =32

abort() was called at PC 0x400da1de on core 1

Backtrace: 0x4008c824:0x3ffb1ed0 0x4008ca55:0x3ffb1ef0 0x400da1de:0x3ffb1f10 0x400da4ff:0x3ffb1f30 0x400dcee5:0x3ffb1f50 0x400e754b:0x3ffb1fb0 0x4008eaa5:0x3ffb1fd0

Rebooting...

oclyke, 2019-03-15:
Hello @guillermoamorin,

Thanks for submitting an issue. I'll try to help you get this working. So first of all I'd like to ask for a little more information.

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

I also notice that your reset pin is set to 27, when in the [Turning a Gateway Into a Device](https://learn.sparkfun.com/tutorials/esp32-lora-1-ch-gateway-lorawan-and-the-things-network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) section, sub-section "Load the Single-Channel Device Example" it shows that the ```.rst``` pin should be 5. I would also double-check that the other configuration options have been successfully transferred into your environment per the tutorial.

Please let me know if that worked and if not then the information above would be very helpful.

jeanole, 2022-01-30:
issued the same problem using the newer version: things4u/ESP-1ch-Gateway as the linked one was marked as old..
but the pin-mapping didnt work out until i found this in ESP-sc-gateway.ino in 30
````
#if defined (ARDUINO_ARCH_ESP32) || defined(ESP32)
#	define ESP32_ARCH 1
#	ifndef _PIN_OUT
#		define _PIN_OUT 4									// For ESP32 pin-out 4 is default //change pin map
#	endif
#elif defined(ARDUINO_ARCH_ESP8266)
````

you have to put your pin-mapping( the one suggested by sparkfun) in loraMode.h under ''#elif _PIN_OUT==4'' or change the defined _PIN_OUT

nseidle, 2022-01-31:
Hi folks - we're archiving this older repo and directing issues and comments over to the current [SparkFun version](https://github.com/sparkfun/ESP32_LoRa_1Ch_Gateway). Please open a new issue if you're still having problems.

Closed 2022-01-31.

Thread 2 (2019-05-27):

Why is there a warning after lora1272 is initialized

richard-ubi, 2019-05-27:
Why is there a warning after lora1272 is initialized
 uint8_t version = readRegister(REG_VERSION);				// Read the LoRa chip version id
 if (version == 0x22) {
        // sx1272
#if DUSB>=2
        Serial.println(F("WARNING:: SX1272 detected"));
#endif
        sx1272 = true;
    }

	else if (version == 0x12) {
        // sx1276?
#if DUSB>=2
            if (debug >=1)
				Serial.println(F("SX1276 starting"));
#endif
            sx1272 = false;
	}

nseidle, 2022-01-31:
Hi folks - we're archiving this older repo and directing issues and comments over to the current [SparkFun version](https://github.com/sparkfun/ESP32_LoRa_1Ch_Gateway).

Closed 2022-01-31.

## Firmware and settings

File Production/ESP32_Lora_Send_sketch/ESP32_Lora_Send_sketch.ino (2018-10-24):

/*******************************************************************************
 * Copyright (c) 2015 Matthijs Kooijman
 *
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
 * This example transmits data on hardcoded channel and receives data
 * when not transmitting. Running this sketch on two nodes should allow
 * them to communicate.
 *******************************************************************************/

#include <lmic.h>
#include <hal/hal.h>
#include <SPI.h>

#if !defined(DISABLE_INVERT_IQ_ON_RX)
#error This example requires DISABLE_INVERT_IQ_ON_RX to be set. Update \
       config.h in the lmic library to set it.
#endif

// How often to send a packet. Note that this sketch bypasses the normal
// LMIC duty cycle limiting, so when you change anything in this sketch
// (payload length, frequency, spreading factor), be sure to check if
// this interval should not also be increased.
// See this spreadsheet for an easy airtime and duty cycle calculator:
// https://docs.google.com/spreadsheets/d/1voGAtQAjC1qBmaVuP1ApNKs1ekgUjavHuVQIXyYSvNc 
#define TX_INTERVAL 2000

// Pin mapping
const lmic_pinmap lmic_pins = {
    .nss = 16,
    .rxtx = LMIC_UNUSED_PIN,
    .rst = 27,
    .dio = {26, 33, 32},
};


// These callbacks are only used in over-the-air activation, so they are
// left empty here (we cannot leave them out completely unless
// DISABLE_JOIN is set in config.h, otherwise the linker will complain).
void os_getArtEui (u1_t* buf) { }
void os_getDevEui (u1_t* buf) { }
void os_getDevKey (u1_t* buf) { }

void onEvent (ev_t ev) {
}

osjob_t txjob;
osjob_t timeoutjob;
static void tx_func (osjob_t* job);

// Transmit the given string and call the given function afterwards
void tx(const char *str, osjobcb_t func) {
  os_radio(RADIO_RST); // Stop RX first
  delay(1); // Wait a bit, without this os_radio below asserts, apparently because the state hasn't changed yet
  LMIC.dataLen = 0;
  while (*str)
    LMIC.frame[LMIC.dataLen++] = *str++;
  LMIC.osjob.func = func;
  os_radio(RADIO_TX);
  Serial.println("TX");
}

// Enable rx mode and call func when a packet is received
void rx(osjobcb_t func) {
  LMIC.osjob.func = func;
  LMIC.rxtime = os_getTime(); // RX _now_
  // Enable "continuous" RX (e.g. without a timeout, still stops after
  // receiving a packet)
  os_radio(RADIO_RXON);
  Serial.println("RX");
}

static void rxtimeout_func(osjob_t *job) {
  digitalWrite(LED_BUILTIN, LOW); // off
}

static void rx_func (osjob_t* job) {
  // Blink once to confirm reception and then keep the led on
  digitalWrite(LED_BUILTIN, LOW); // off
  delay(10);
  digitalWrite(LED_BUILTIN, HIGH); // on

  // Timeout RX (i.e. update led status) after 3 periods without RX
  os_setTimedCallback(&timeoutjob, os_getTime() + ms2osticks(3*TX_INTERVAL), rxtimeout_func);

  // Reschedule TX so that it should not collide with the other side's
  // next TX
  os_setTimedCallback(&txjob, os_getTime() + ms2osticks(TX_INTERVAL/2), tx_func);

  Serial.print("Got ");
  Serial.print(LMIC.dataLen);
  Serial.println(" bytes");
  Serial.write(LMIC.frame, LMIC.dataLen);
  Serial.println();

  // Restart RX
  rx(rx_func);
}

static void txdone_func (osjob_t* job) {
  //rx(rx_func);
}

// log text to USART and toggle LED
static void tx_func (osjob_t* job) {
  // say hello
  tx("Hello, world!", txdone_func);
  // reschedule job every TX_INTERVAL (plus a bit of random to prevent
  // systematic collisions), unless packets are received, then rx_func
  // will reschedule at half this time.
  os_setTimedCallback(job, os_getTime() + ms2osticks(TX_INTERVAL + random(500)), tx_func);
}

// application entry point
void setup() {
  Serial.begin(115200);
  Serial.println("Starting");
  #ifdef VCC_ENABLE
  // For Pinoccio Scout boards
  pinMode(VCC_ENABLE, OUTPUT);
  digitalWrite(VCC_ENABLE, HIGH);
  delay(1000);
  #endif

  pinMode(LED_BUILTIN, OUTPUT);

  // initialize runtime env
  os_init();

  // Set up these settings once, and use them for both TX and RX

#if defined(CFG_eu868)
  // Use a frequency in the g3 which allows 10% duty cycling.
  LMIC.freq = 869525000;
#elif defined(CFG_us915)
  LMIC.freq = 902300000;
#endif

  // Maximum TX power
  LMIC.txpow = 27;
  // Use a medium spread factor. This can be increased up to SF12 for
  // better range, but then the interval should be (significantly)
  // lowered to comply with duty cycle limits as well.
  LMIC.datarate = DR_SF9;
  // This sets CR 4/5, BW125 (except for DR_SF7B, which uses BW250)
  LMIC.rps = updr2rps(LMIC.datarate);

  Serial.println("Started");
  Serial.flush();

  // setup initial job
  //os_setCallback(&txjob, tx_func);
  pinMode(0, INPUT_PULLUP);
}

void loop() {
  // execute scheduled jobs and events
  os_runloop_once();
  if (digitalRead(0) == LOW) {
    while(digitalRead(0) == LOW) ;
    tx("Hello, world!", txdone_func);
  }
}

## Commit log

2018-07-18 Hardware commit x01
    [esp32_lora_gateway-Panel.GBL, esp32_lora_gateway-Panel.GBO, esp32_lora_gateway-Panel.GBP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]
2018-07-25 Changing blue LED to green.
    [esp32_lora_gateway-Panel.brd, esp32_lora_gateway.brd, esp32_lora_gateway.sch]
2018-08-02 Moving part value text for assembly sheet. Set sch version.
    [esp32_lora_gateway-Panel.GBL, esp32_lora_gateway-Panel.GBO, esp32_lora_gateway-Panel.GBP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]
2018-08-02 Add x01 schematic.
2018-08-02 Adding example device sketch and arduino-esp32 core files.
2018-08-02 Adding ESP32 and RFM95 documentation

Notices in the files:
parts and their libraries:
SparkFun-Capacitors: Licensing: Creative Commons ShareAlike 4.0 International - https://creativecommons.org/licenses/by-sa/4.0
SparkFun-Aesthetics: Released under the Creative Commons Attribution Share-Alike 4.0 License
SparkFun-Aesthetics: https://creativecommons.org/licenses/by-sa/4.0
